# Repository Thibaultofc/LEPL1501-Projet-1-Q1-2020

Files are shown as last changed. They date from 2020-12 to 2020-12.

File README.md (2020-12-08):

# LEPL1501-Projet-1-Q1-2020
LEPL1501 - PROJET P1 – Q1 2020

Durant ce projet, nous avons été amené, par groupes de 6, à concevoir une grue flottante permettant d'assembler des éoliennes en mer. De surcroit, nous avons développé un programme permettant d'obtenir l'oscillation de la plateforme flottante lors du déplacement d'une charge. Finalement, nous avons conceptualisé certaines pièces sur Fusion 360 et nous les avons imrpimées à l'aide d'une imprimante 3D.

Les membres du groupe 11.27 sont *Thibault Lootvoet, Romain Loncour, Hugolin Louis, Nicolas Luyckx, Safiya Nouidei* et *Clara Nys*

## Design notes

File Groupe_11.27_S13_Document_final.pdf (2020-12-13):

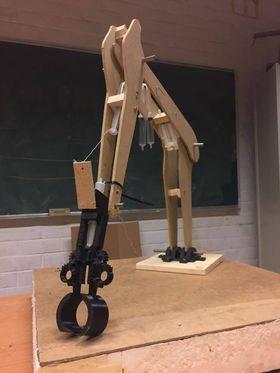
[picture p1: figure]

## LEPL1501 – PROJET P1 – Q1

### Décembre 2020

Groupe 11 .27 :

Thibault Lootvoet, Romain Loncour, Hugolin Louis,

Nicolas Luyckx, Safiya Nouidei et Clara Nys

## Table des matières:

## Introduction

Il y a maintenant près de deux mois, la famille de Bremaecker, persuadée que l'énergie éolienne est

encore trop peu utilisée, a demandé aux étudiants de l’EPL en Bac 1, de conceptualiser une grue ainsi

qu’une barge permettant d’assembler des éoliennes en pleine mer. Après avoir établi notre cahier des

charges, (repris à la page suivante), nous, le groupe 11.27, composé de Romain, Clara, Hugolin,

Nicolas, Thibault et Safiya, avons donc commencé à réfléchir à différents modèles.

En équipe, nous avons dû établir dans un premier temps toutes sortes de documents (To Do, cahier

des charges, organisation de l’équipe, …) afin que la progression du groupe se fasse dans les meilleures

conditions.

Après de nombreuses réflexions individuelles suivies d’échanges, nous en sommes arrivés à un modèle de grue fonctionnel que nous avons pu réaliser ensemble dans les délais et qui a parfaitement répondu aux exigences attendues par la famille, comme vous le verrez dans la conclusion.

Vous trouverez dans ce recueil toutes les parties du travail qui ont permis d’arriver au résultat escompté. Du cahier des charges à la construction du prototype, en passant par les schémas et le code informatique, chaque étape du processus est retranscrite dans ce document.

## Cahier des charges

Equipe 11.27

### Cahier des charges d’une grue

### flottante permettant de construire

### une éolienne

Date : 17-11-

2020

Mise à jour | Remplace : 2 Version du :
Date | Origine

Contexte : La famille De Bremaecker, très sensible aux questions environnementales et en particulier liées

à la production d’énergie, pense que l’énergie éolienne est trop peu utilisée. Ils décident donc de

sponsoriser un concours visant à promouvoir la recherche dans le domaine de la conception de grues

17-11-2020 | Equipe | Fonctions principales FP1. Pouvoir assembler toutes les parties d’une éolienne. FP2. La grue doit pouvoir être légère, facilement transportable, montable et
17-11-2020 | Equipe | Critères et niveaux des FP 1. L’éolienne a une hauteur totale de 210m, et 122m sans les pales. La grue doit pouvoir atteindre 122m.¹ 2. La grue doit pouvoir soulever jusqu’à 90 tonnes.² 3. Le grappin doit pouvoir saisir toutes les parties de l’éolienne y compris les
17-11-2020 | Equipe | Fonctions de Contraintes FC1. La grue doit être capable de flotter dans l’eau sans être submergée et tout en restant stable. FC2. La grue doit pouvoir résister aux intempéries en mer (températures, vent,
17-11-2020 | Equipe | Critères et niveaux des FC 1. La grue doit pouvoir résister à des températures allant de -19 degrés Celsius à 34°C⁴ 2. La pluviométrie s’élève jusqu’à 110.9mm.⁵ 3. La grue doit pouvoir résister à des rafales de vent allant jusqu’à 150km/h.⁶ 4. La hauteur des vagues maximales peut atteindre jusqu’à 20m.⁷

1 https://cpdp.debatpublic.fr/cpdp-eolienmer-pdlt/quelles-sont-caracteristiques-techniques-eoliennes-envisagees.html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,à%20environ%203%20600%20kg.
2 Idem 1
3 Idem 1
4 https://planificateur.a-contresens.net/europe/belgique/wallonie/la_cote/2793689.html
5 http://portail2.reseau-concept.net/Upload/siceco/fichiers/guide_enr_eolien.pdf
6 https://www.ifremer.fr/sextant_doc/dcsmm/documents/Evaluation_initiale/MMN/EE/MMN_EE_01_Climatologie_marine.pdf
7 http://www.geoclimat.org/2016/12/record-hauteur-vague-atlantique-nord.html

## Commentaires sur le CDC

Concernant son évolution, notre cahier des charges du début du projet était assez complet

sans pour autant nous restreindre donc nous avons décidé de le garder tel qu’il était. Cependant,

nous avons ajouté des sources et nous avons précisé les critères et niveaux des fonctions de

contraintes.

## Schéma cinématique de la grue réelle

Explication du schéma : Le schéma cinématique est composé de trois parties différentes à savoir le

système de rotation, le bras mécanique et le grappin. Ce dernier a été représenté de face par souci

de compréhension. Tous les mouvements que la grue effectue sont déclenchés par des seringues

représentées sur ce schéma comme des vérins hydrauliques. Le système de rotation transforme le

mouvement rectiligne de la seringue en mouvement de rotation à l’aide d’une liaison pivot entre la

seringue et un cylindre qui sort de l’engrenage. Il s’agit d’un système bielle-manivelle présent

notamment dans les moteurs à explosion. Cet engrenage en mouvement enclenche le mouvement

d’un autre engrenage sur lequel est disposé la grue. La grue en elle-même est constituée de 3 bras

mobiles reliés entre eux par des liaisons sphériques à doigt. Le grappin est composé d’une

crémaillère reliée à des engrenages encore une fois reliés à des engrenages sur lesquels sont fixées

les pinces du grappin.

## Conception du prototype

Premières idées

Plusieurs idées ont été émises et nous avons tous contribué à la conception de notre grue

finale. Au fil du projet, nous avons su rassembler nos idées pour créer un prototype que nous avons

pu peaufiner.

Trois étudiants avaient conceptualisé un grappin lors de la S4 et les trois autres une grue.

Nous nous sommes basés sur ces schémas pour élaborer notre premier grappin et la première

version de la grue.

La modélisation du grappin se fit en parallèle de la modélisation de la grue ce qui engendra

une incompatibilité des deux parties. Le règlement du concours stipulait que les morceaux

d’éoliennes étaient à prendre couchées et à redresser verticalement. Notre grappin était censé être

suspendu par des câbles à la grue mais malheureusement cela ne permettait pas de faire pivoter le

grappin.

Cheminement

La grue du pré-jury n’avait aucun lien avec notre grue finale. Ce sera explicité plus loin dans

le rapport. Comme expliqué précédemment, le grappin, bien que déjà modélisé et imprimé, s’est

révélé ne pas être la solution optimale pour le jury final. Voici tout de même quelques images de

celui-ci :

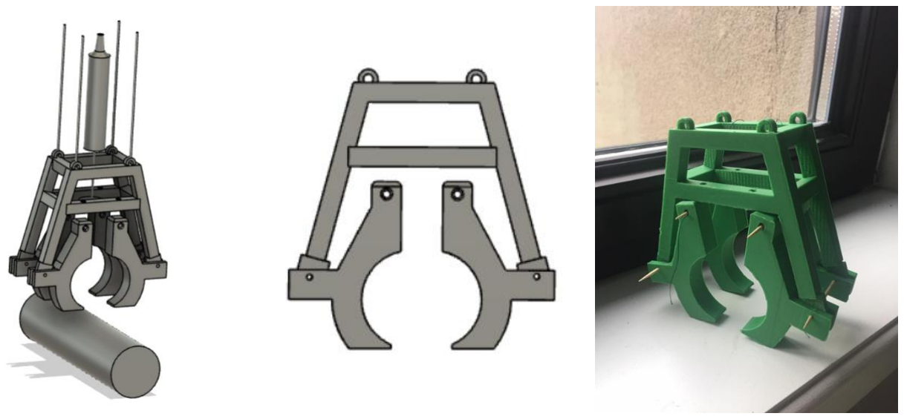
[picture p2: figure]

Après le pré-jury, nous avons repensé toute la modélisation pour remédier aux soucis rencontrés. Notre prototype se compose de quatre parties principales : le grappin⁹
, le bras articulé,

le système de rotation de la grue et la barge. Nous avons décidé qu’il serait le plus optimum de

construire un bras articulé. Constitué de trois parties et actionnable grâce au système de vérins, il

est posé sur le système de rotation. Le système de rotation fonctionne grâce à un engrenage qui est

enclenché par un autre engrenage qui est lui-même entrainé par le mouvement de la seringue. Ce

système est comparable aux roues d’une locomotive à vapeur.

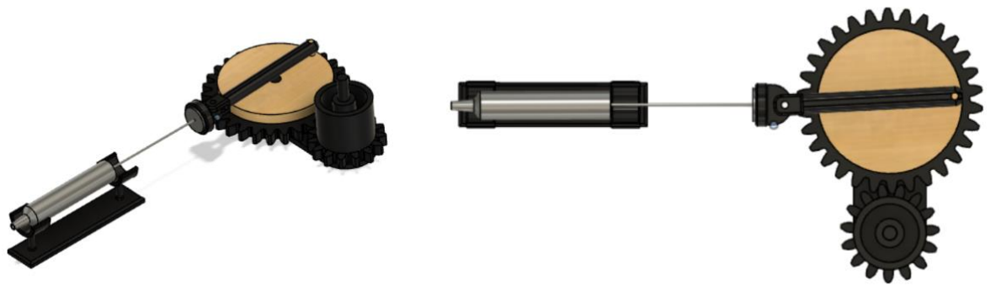
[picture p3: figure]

Le grappin, quant à lui, est également basé sur un dispositif d’engrenages et de crémaillère.

Voici le lien permettant d’accéder aux plans d'impression du grappin ( 6 fichiers stl ) : https://github.com/Thibaultofc/LEPL1501-Projet-1-Q1-2020

9 https://www.thingiverse.com/thing:2917515 Nous avons modifié cette pince afin de créer notre grappin.

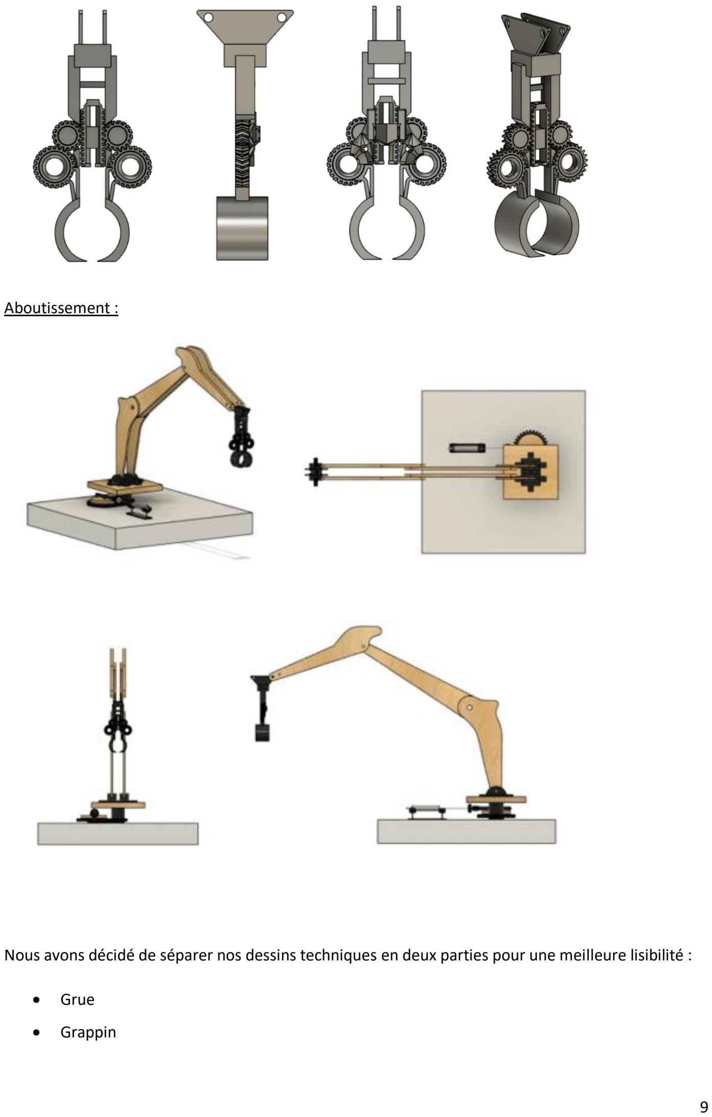
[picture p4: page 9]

Aboutissement :

Nous avons décidé de séparer nos dessins techniques en deux parties pour une meilleure lisibilité :

- Grue
- Grappin

Le grappin a dû être simplifié vu sa complexité. Les cotes des engrenages sont les cotes utilisées

pour caractériser plusieurs cercles et les cotes de certaines parties beaucoup trop complexes n’ont

pas été notées.

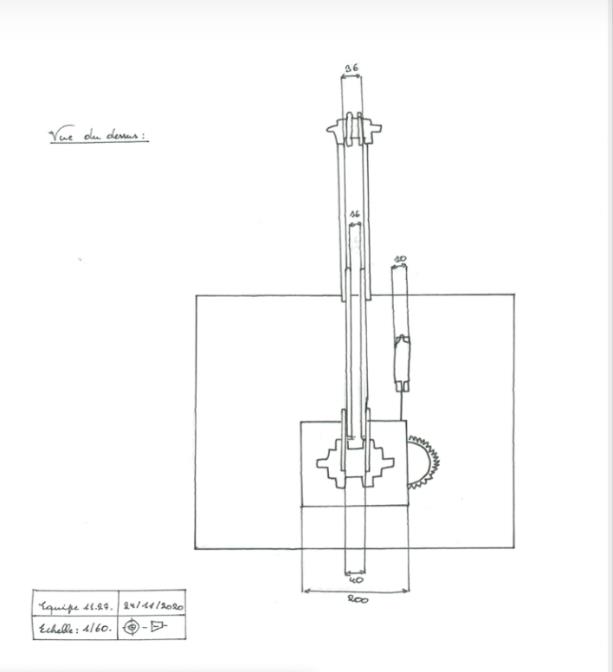
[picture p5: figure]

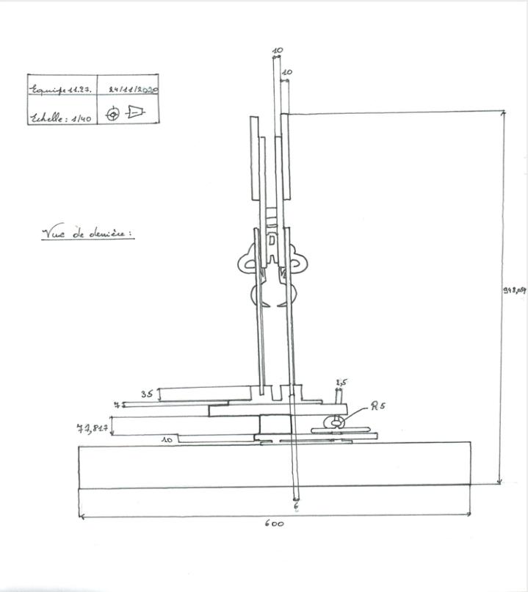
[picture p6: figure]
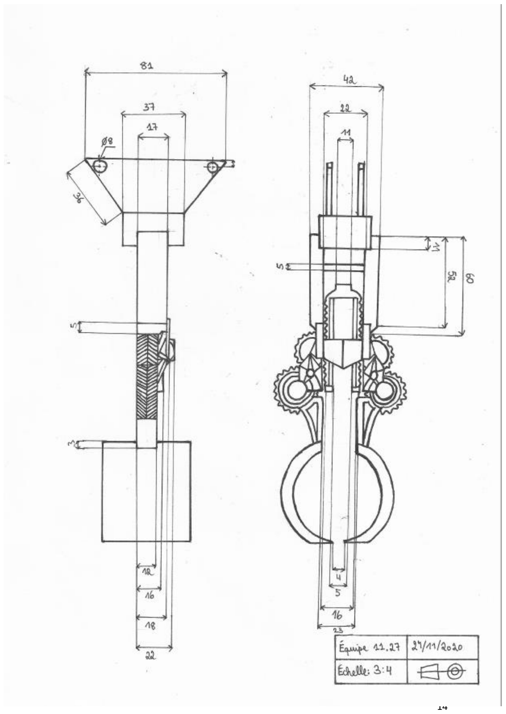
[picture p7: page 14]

## Modèle physique

Afin de modéliser le comportement de l’inclinaison de notre grue lorsqu’elle déplace une certaine

charge à une certaine distance, nous

avons procédé en deux étapes. De

plus, nous avons simplifié la

représentation de la grue afin de

simplifier les calculs tout en gardant

une précision acceptable. Le modèle

se compose d’une plateforme

flottante (m1), d’une charge placée

sur la plateforme (m2) et d’une

charge mobile (m3) à une certaine distance du centre de la plateforme (d).

Nous avons considéré que m2 était la masse du bras. Malgré le fait que nous avons placé la base

du bras à une extrémité, nous considérons quand même que m2 est placé au centre car le bras,

contrairement au modèle n’est pas un point et qu’après une analyse de notre prototype sur

Fusion 360, le centre de masse se situait approximativement au centre de la barge. Par contre, lorsque

nous déplaçons une masse nous considérons que cette charge est la somme de sa masse et de la

moitié du bras. De plus, nous considérons que l’angle au temps t = 0 est de 0 degrés.

Dans un premier temps, nous avons cherché à connaitre l’enfoncement de la plateforme dans

l’eau (1) et l’angle maximal que pouvait subir la plateforme avant d’être submergée en fonction de la

masse totale du système, de la charge déplacée et de la distance à laquelle celle-ci se situe du milieu

de la barge (2). L’équation (3) représente l’angle auquel la plateforme est en situation de soulèvement.

Le symbole φ représente la masse volumique du liquide dans lequel est plongé la plateforme (de l’eau dans ce cas-ci φ = 997 kg/m³
).

ℎc =

m1 + m2
L

2 ⋅ φ

(1)

θmax = arctan (

2(ℎ1 − ℎc

)
L
) | (2)

θs = arctan (

2ℎc
L
) | (3)

Dans un second temps, nous avons cherché à représenter le mouvement oscillatoire de la

plateforme lors du déplacement de la charge mobile (m3). Cette oscillation nous est donnée par

l’équation linéaire de second ordre suivante (4). I représente le moment d’inertie de la plateforme avec la grue, D représente le coefficient d’amortissement et C représente la somme des couples de

chavirement (5) et de redressement (6).

I

d

2θ
dt

2 + D

dθ
dt = C | (4)
Ca = m3gd′ | (5)
Cr = (m1 + m2)g|xc − xg| | (6)

Afin de calculer la distance d

′
(représentant la distance entre la masse et le centre en

fonction de l’angle) nous utilisons l’équation (7) qui est simplement un problème trigonométrique.

Afin de calculer les positions selon l’axe X du centre de gravité et du centre de poussée (xc et xg),

nous utilisons les équations (8) et (9).

d

′ = dcos(θ) − ℎ3sin(θ) | (7)

xg =

m1 (

ℎ1
2

− ℎc) + m2
(ℎ1 + ℎ2 − ℎc

)
m1 + m2
sin(θ) | (8)

xc =

(12)ℎc

2 − L

2
(24)ℎc

sin(θ) −

L

2
(24)ℎccos(θ)
tan(θ) | (9)

Pour les valeurs des différents paramètres, m1, m2, L, ℎ1, ℎ2 sont des paramètres

inhérents à notre grue tandis que m3, ℎ3, d, φ sont des paramètres dépendant du concours.

Finalement, nous avons considéré que g valait 9.81 m/s²
| Paramètres | Valeur / plage de valeurs
Paramètres de la grue | m1 Masse de la barge | 3 kg
| m2 Masse de la grue | 1.5 kg
| L Largeur de la barge | 0.6 m
| ℎ1 Hauteur de la barge | 0.15 m
| ℎ2 Hauteur de la grue | 0.5 m
Paramètres du concours | m3 Masse déplacée | 0 – 0.4 kg
| ℎ3 Hauteur de la masse déplacée | 0 – 0.6 m
| d Distance entre la grue et la masse déplacée | 0.6 – 1 m
| φ Masse volumique du liquide | 997 kg/m³ pour l’eau

## Description du fonctionnement du programme informatique

Le programme fonctionne de manière « pas-à-pas », c’est-à-dire qu’à chaque itération, le

paramètre dont toutes les équations dépendent (i dans ce cas-ci) est augmenté de 0.01 secondes.

Lorsque nous graphons la matrice dans laquelle nous stockons les données des angles en fonction du

temps, nous obtenons une sinusoïdale amortie. Afin d’être plus précis, nous pourrions diminuer la

valeur par laquelle le paramètre est augmenté, cependant dans nos tests, la précision donnée grâce à 0.01 secondes était suffisante (delta de l’angle de l’ordre de 10⁻⁴ degrés) et le temps de calcul passe

d’environ 1 seconde à plus de 10 secondes.

Le moment d’inertie a été déterminé grâce à Fusion360 et le coefficient d’amortissement a

été choisi en fonction de nos mesures en laboratoire (nous avons remarqué que la barge se stabilisait

après 10 secondes environ et par essai erreur nous avons trouvé le coefficient). Les autres paramètres

modifiables sont la masse déplacée, de la barge et de la grue, la distance à laquelle la masse est

déplacée, la largeur et hauteur de la base ainsi que la hauteur de la grue et de la masse. Le pas, la

durée et la masse volumique du liquide sur lequel la barge flotte peuvent aussi être modifiés.

## Simulations du mouvement d’oscillation

https://github.com/Thibaultofc/LEPL1501-Projet-1-Q1-2020

# Programme de simulation informatique produisant différents graphiques # Groupe 11.27

# Thibault, Clara, Nicolas, Romain, Hugolin et Safiya

import math
import matplotlib.pyplot as plt
import numpy as np

### Constantes

g = 9.81 | # Constante de gravitation [m/s^2]

### Paramètres du système

D = 10 | # coef d'amortissement
I = 6.596 | # Moment d'inertie [kg.m^2]
m = .4 | # Masse déplacée [kg]
m1 = 3 | # Masse de la barge [kg]
m2 = 1.5 | # Masse de la grue [kg]
mtot = m+m1+m2 | # Masse totale [kg]
d = 0.85 | # Distance [m]
L = 0.6 | # Largeur de la base carrée [m]
h1 = 0.15 | # Hauteur de la base [m]
h2 = 0.5 | # Hauteur du chargement [m]
h3 = 0.1 | # Hauteur de la masse portée [m]
hc = mtot/(L**2*997) | # 997 étant la masse volumique de l'eau [m]

### Paramètres de la simulation

step = 0.01 | # Pas (dt) [s]
end = 20 | # Durée [s]
x_0 = 0 | # Angle initial [rad]
x1_0 = 0 | # Vitesse angulaire initiale [rad/s]
x2_0 = 0 | # Accélération angulaire initiale [rad/s**2]
sum_c_0 = 0 | # Somme des couples initiaux [N.m]
Ca_0 = -m*g*d | # Couple initiale de chavirement [N.m]
Cr_0 = 0 | # Couple de redressement initial [N.m]
dist_0 = 0 | # Distance entre le centre de gravité et le centre de poussée selo
n X initiale [m]

### Matrices de stockage des données

t = np.arange(0, end, step) # Durée [s]
x = np.empty_like(t) | # Angle [rad]
x1 = np.empty_like(t) | # Vitesse angulaire [rad/s]
x2 = np.empty_like(t) | # Accélération angulaire [rad/s**2]
sum_c = np.empty_like(t) | # Somme des couples [N.m]
Ca = np.empty_like(t) | # Couple de chavirement [N.m]
Cr = np.empty_like(t) | # Couple de redressement [N.m]
dist = np.empty_like(t) | # Distance entre la barge et la charge [m]

xc = np.empty_like(t) | # Centre de poussée, coordonnée du x [m]
xg = np.empty_like(t) | # Centre de gravité, coordonnée du x [m]
distance = np.empty_like(t) # Distance en xc et xg [m]

def simulation(m):

# Equation: I*ang'' + D*ang' = C

### Paramètres initiaux de l'équation

x[0] = x_0
x1[0] = x1_0
x2[0] = x2_0
sum_c[0] = sum_c_0
Ca[0] = Ca_0
Cr[0] = Cr_0
dist[0] = dist_0

dt = step
P = mtot*g
Pa = m*g

# calcul pas-à-pas de l'EDO de second ordre. On stocke toutes les données dans chaque matrice res pective.

for i in range(len(t)-1):

dist[i+1] = d*math.cos(x[i])-h3*math.sin(x[i]) | # Distance
Ca[i+1] = -m*g*dist[i] | # Couple de chavirement

xc[i+1] = ((12*hc**2-
L**2)/(24*hc))*math.sin(x[i]) - (L**2/(24*hc*math.cos(x[i])))*math.tan(x[i]) # C entre de poussée, coordonnée en x
xg[i+1] = ((m1*(h1/2-hc)+m2*(h2+h1-
hc))/(mtot))*math.sin(x[i]) | # Centre de gravi
té, coordonnée en x
distance[i+1] = xc[i] - xg[i] | # Distance entre xc et xg

Cr[i+1] = mtot*g*abs(distance[i]) # Couple de redressement
sum_c[i+1] = Ca[i] + Cr[i] | # Somme des couples
x2[i] = (sum_c[i]-D*x1[i])/I | # Accélération angulaire
x1[i+1] = x1[i] + x2[i] * dt | # Vitesse angulaire
x[i+1] = x[i] - x1[i] * dt | # Angle
x2[i+1] = x2[i]

### Paramètres du graphique

angle_max = math.atan(2*(h1-hc)/L) | # Angle max
angle_s = math.atan(2*hc/L) | # Angle de soulèvement

### Variable permettant de passer de radians en degrés

rad_to_deg = 57.29578

r = rad_to_deg

### Graphique des différentes masses [kg] en fonction de la distance [m] à laquell e elles sont déplacées

def graphiques_distances_masses():

simulation(m)

# Traçage de chaque fonction pour chaque masse

simulation(1)
x_values = [0, d]
y_values = [x[0]*r, x[20]*r] plt.plot(x_values,y_values,label='m = 1kg') plt.legend()

simulation(2)
y_values2 = [x[0]*r, x[20]*r] plt.plot(x_values,y_values2,label='m = 2kg') plt.legend()

simulation(3)
y_values3 = [x[0]*r, x[20]*r] plt.plot(x_values,y_values3,label='m = 3kg') plt.legend()
simulation(4)
y_values4 = [x[0]*r, x[20]*r] plt.plot(x_values,y_values4,label='m = 4kg') plt.legend()

simulation(5)
y_values5 = [x[0]*r, x[20]*r] plt.plot(x_values,y_values5,label='m = 5kg') plt.legend()

# Paramètres généraux du graphique

plt.plot([0,end], [angle_max*r,angle_max*r], '--
r', label='submersion') # Ligne en pointillé qui marque le submersion (positif) plt.plot([0,end], [-angle_max*r,-angle_max*r], '--
r') | # Ligne en pointillé qui marque le submersion (négatif)
plt.plot([0,end], [angle_s*r,angle_s*r], '--
b', label='soulèvement') # Ligne en pointillé qui marque le soulèvement (positi f)
plt.plot([0,end], [-angle_s*r,-angle_s*r], '--
b') | # Ligne en pointillé qui marque le soulèvement (négatif)

plt.xlabel('Distance (m)')
plt.ylabel('Angle (º)')
plt.xlim(0,d)
plt.ylim(0,angle_max*r+1)
plt.show()

### Graphique de l'angle [degrés] en fonction du temps [s]

def graphique_angle_deg():

# Paramètres généraux du graphique

simulation(m)
plt.plot(t,x*r)
plt.xlim(0,end)
plt.xlabel('Temps (s)')
plt.ylim(0,angle_max*r+1)
plt.ylabel('Angle (º)')

plt.plot([0,end], [angle_max*r,angle_max*r], '--
r', label='submersion') # Ligne en pointillé qui marque le submersion (positif) plt.plot([0,end], [-angle_max*r,-angle_max*r], '--
r') | # Ligne en pointillé qui marque le submersion (négatif)
plt.plot([0,end], [angle_s*r,angle_s*r], '--
b', label='soulèvement') # Ligne en pointillé qui marque le soulèvement (positi f)
plt.plot([0,end], [-angle_s*r,-angle_s*r], '--
b') | # Ligne en pointillé qui marque le soulèvement (négatif)

plt.show()

### 3 graphiques :

# | 1. Angle [rad] en fonction du temps [s]

# | 2. Vitesse angulaire [rad/s] en fonction du temps [s]

# | 3. Accélération angulaire[rad/s**2] en fonction du temps [s]

def graphiques():

simulation(m)

# Sous-graphique : 1. Angle [rad] en fonction du temps [s]

plt.figure(1)

plt.subplot(3,1,1)
plt.plot(t,x, label="Angle")
plt.legend()
plt.xlim(0,end)

plt.plot([0,end], [angle_max,angle_max], '--
r', label='submersion') # Ligne en pointillé qui marque le submersion (positif) plt.plot([0,end], [-angle_max,-angle_max], '--
r') | # Ligne en pointillé qui marque le submersion (négatif)
plt.plot([0,end], [angle_s,angle_s], '--
b', label='soulèvement') # Ligne en pointillé qui marque le soulèvement (positi f)
plt.plot([0,end], [-angle_s,-angle_s], '--
b') | # Ligne en pointillé qui marque le soulèvement (négatif)
plt.ylabel('Angle \n (rad)',fontsize = 5)

# Sous-graphique : 2. Vitesse angulaire [rad/s] en fonction du temps [s]

plt.subplot(3,1,2)
plt.plot(t,x1,'g', label="Vitesse angulaire")
plt.legend()
plt.xlim(0,end)

plt.ylabel('Vitesse angulaire \n (rad/s)',fontsize = 5)

# Sous-graphique : 3. Accélération angulaire[rad/s**2] en fonction du temps [s]

plt.subplot(3,1,3)
plt.plot(t,x2,'#e3902b', label="Accélération angulaire") plt.legend()
plt.xlim(0,end)
plt.ylabel('Accélération angulaire \n (rad/s^2)',fontsize = 5)

# Paramètres généraux

plt.xlabel('Temps (s)')
plt.show()

### Diagramme de phase : graphique représentant la vitesse angulaire [rad/s] en fo nction de l'angle [rad]

def diagramme_de_phase():

# Paramètres généraux du graphique

simulation(m)
plt.title("Diagramme de phase") plt.plot(x, x1,linewidth=0.75) plt.xlabel("Angle (rad)")
plt.ylabel("Vitesse angulaire (rad/s)") plt.show()

### Programme principal

graphiques_distances_masses() graphique_angle_deg()
graphiques()
diagramme_de_phase()

## Graphiques

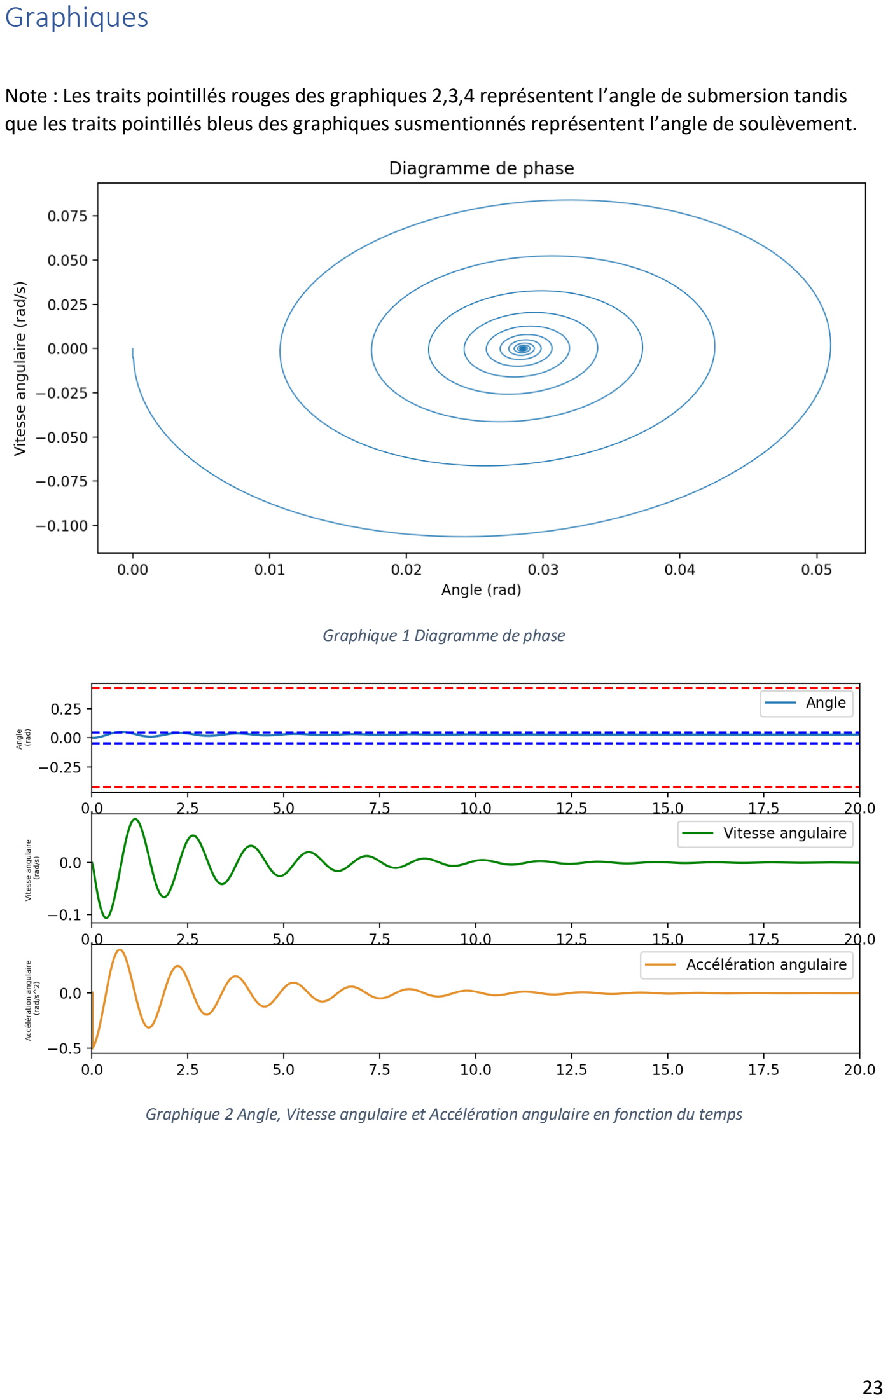
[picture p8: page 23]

Note : Les traits pointillés rouges des graphiques 2,3,4 représentent l’angle de submersion tandis que les traits pointillés bleus des graphiques susmentionnés représentent l’angle de soulèvement.

Graphique 1 Diagramme de phase

Graphique 2 Angle, Vitesse angulaire et Accélération angulaire en fonction du temps

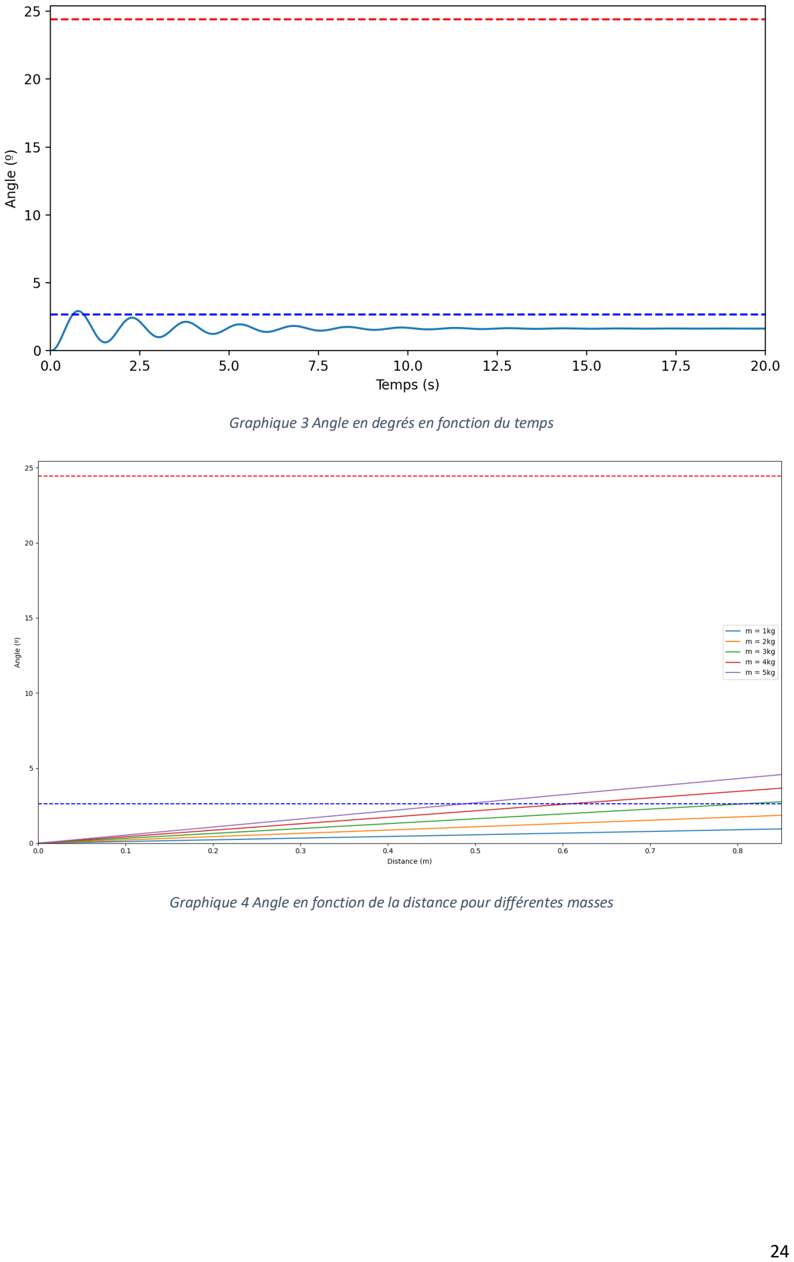
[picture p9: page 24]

Graphique 3 Angle en degrés en fonction du temps

Graphique 4 Angle en fonction de la distance pour différentes masses

## Discussion des résultats

Dans un premier temps, nous n’avions pas compris qu’au concours, l’inclinomètre serait remis

à zéro donc nous obtenions un angle bien trop élevé (entre 2 et 3 degrés alors que l’inclinomètre

indiquait 1.7 degrés). Après une modification, nous obtenons un angle de 1.66 degrés au temps t = 20,

résultat remarquablement proche de la réalité, malgré une simplification du modèle.

Le graphique 4, représentant l’angle en degrés en fonction de la distance, nous renseigne sur

le fait que notre barge ne risquait pas d’être submergée et qu’en soulevant les futs ou la tête de

l’éolienne, la barge n’allait pas être en soulèvement au temps t = 20 et c’est ce qu’il s’est passe en

réalité. En revanche, les graphiques 2 et 3 prévoyaient que la barge allait être en soulèvement lors de

la première oscillation et en pratique, un tel comportement n’a pas été observé.

En conclusion, notre modèle physique semble permettre de prédire l’angle final lors du

déplacement d’une masse, en revanche, il est imprécis quant aux oscillations. Afin d’améliorer les

résultats, il pourrait être intéressant de calculer le coefficient d’amortissement de manière analytique.

## Construction de la maquette

Pour le pré-jury, nous devions avoir une grue permettant de soulever une pièce de la grue a

une hauteur de 10 cm et avoir au moins 2 degrés de liberté. Pour répondre à ces exigences, nous

avions décidé de nous pencher sur un modèle de grue utiliser par les constructeurs à travers le

monde. C’est un modèle de bras télescopique se soulevant à l’aide d’un vérin hydraulique situé à la

base du bras. Un ancien jouet, redécouvert par un membre du groupe, nous a servi à faire le bras de

notre maquette. En effet, ce vieux jouet n’était qu’autre qu’une grue miniature. Il était en plastique

et reprenait exactement la même structure que les grues réelles. Il nous a donc paru judicieux de

l’utiliser car ce composant reprenant les caractéristiques souhaitées, la légèreté, la rigidité et la

facilité d’utilisation. La figure 1 permet mieux de visualiser notre maquette.

Ensuite, nous avons dû réfléchir à modèle de grappin. Nous

n’allons pas réexpliquer tout le cheminement que nous avons dû faire

pour aboutir à ce grappin mais en quelques lignes, le voici. Le grappin

devait donc pouvoir agripper un fut de 5 cm de diamètre et pouvoir

maintenir une pression suffisante pour que celui-ci ne glisse pas. Notre

premier modèle fut donc un modèle a « traction », autrement dit, la

force appliquée venait de la rétraction de la seringue. Il s’est avéré par

la suite que ce n’était pas le modèle le plus optimal. Ainsi, nous avons

décidé de changer de modèle mais ceci vous a déjà expliqué plus haut.

Comme le modèle définitif, le premier a été imprimé en PLA à l’aide

d’une imprimante 3D.

Avec ceci, nous n’avions qu’un degré de liberté, le verin à

la base servant à monter et descendre le bras (celui du grappin

est exclu). Pour palier a ce manque, nous avons ecidé d’incruster

un système de rotation. Celui-ci est situé a la base du bras et est

en réalité une grosse bobine de fil. En tirant à la main sur le fil

enroulé, il se déroule et entraine avec lui la bobine. Afin de

pouvoir faire tourner la grue à 360° et dans les deux sens

(horloger et anti-horloger), nous avons enroulé le deuxieme fil

dans le sens opposé au premier.

Enfin, voici un lien permettant de visionner une vidéo de notre maquette en action lors du pré-

jury :Test maquette : https://youtu.be/BV1qX7-c0VU

Figure 2 : modèle de grappin pour le pré-jury

Figure 3 : vue de haut de la maquette de pré-jury

## Construction du prototype

Dans un premier temps, nous nous sommes concentrés sur la

construction de la barge. Le matériau utilisé en guise de flotteur est un

panneau d’isolation. Comme le reste des éléments constituant cette

plateforme, il a été récupéré.

Nous avons choisi d’utiliser ce panneau isolant car tout d’abord, il est

de récupération. Il va de soit de, dans un premier temps, privilégier

l’utilisation de matière se trouvant en notre possession. Ensuite, ce matériau

a pour avantage d’être inaltérable à l’eau, ce qui n’est pas négligeable dans

notre cas. Enfin, il est relativement léger. En effet, il a une masse volumique

d’environ 30 kg/m³. Grâce à cela et sans poids supplémentaire, la barge

s’enfonce d’à peine 3 millimètres.

Dans un second temps, nous avons décidé d’imprimer la plupart des

pièces techniques en PLA, à l’aide d’une imprimante 3D. Ainsi, les

engrenages, axes, pieds de la grue, etc. ont été imprimés en 3D. Ce procédé

nous a permis de gagner du temps, de la précision et de l’énergie. Ensuite, le

matériau composant en grande partie la grue en tant que telle est le MDF.

Le MDF est un panneau composite de fibre de bois. Pour

notre utilisation, cela nous convenait parfaitement car le

prix était tout à fait abordable, la solidité suffisante et le

poids adéquat. De plus c’est un matériau simple

d’utilisation car il nous suffit d’une scie pour en faire ce que

l’on veut.

Dans une première idée, nous voulions découper

au laser les pièces dans des panneaux de bois.

Malheureusement, le COVID 19 ne nous a pas facilité la

tâche et a rendu impossible cette idée. Nous avons alors dû

découper les pièces manuellement. Finalement, en

comparant le prototype actuel avec la maquette réalisé en

S6, nous pouvons affirmer que notre modèle final est plus

efficace, plus esthétique et répond aux contraintes

imposées par notre cahier des charges.

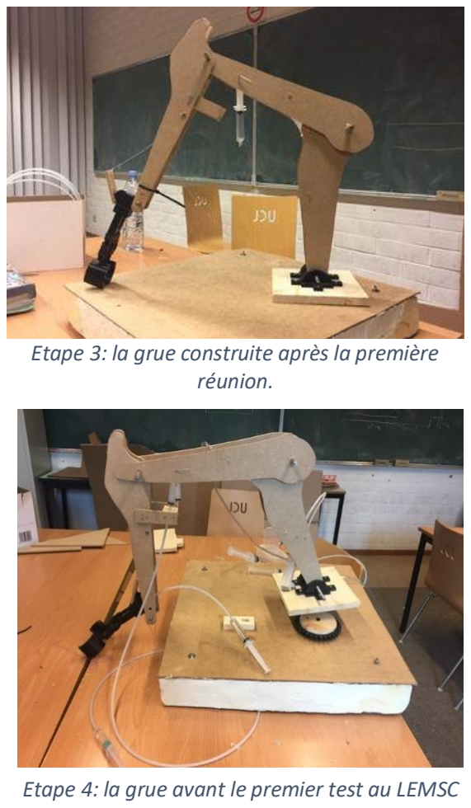
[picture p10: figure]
réunion.

Etape 3: la grue construite après la première

Etape 4: la grue avant le premier test au LEMSC

Etape 2: mise en place des éléments constitutifs de la grue

Les liens ci-dessous permettent de visionner les vidéos de notre prototype en action :

Test à sec : https://youtu.be/CDDwnzrw4-g

Test au LEMSC : https://youtu.be/yUPi21tc59Q

Vidéo du concours : https://youtu.be/ZDqFZTVV2L4

## Organisation de l’équipe

### - Contrat d’équipe :

1. Arriver à l’heure
2. Ne pas être absent de manière injustifiée
3. Respecter les échéances
4. Travailler de la manière la plus optimale
5. Respecter le groupe
6. Ecouter du groupe
7. Eviter les pertes de temps
8. Participer aux décisions
9. Participer activement au travail collaboratif

### - Commentaire :

Le contrat d’équipe a été globalement bien respecté par tous les membres du groupe tout au long

de ce projet. Nous avons eu, durant les premières semaines quelques soucis au niveau de

l’organisation et de la communication ce qui nuisait à l’optimisation du travail et du temps. Il nous est

arrivé de quelques fois rendre des travaux légèrement après l’heure d’échéance à cause de ce

problème d’organisation. Cependant, au fils des semaine et en apprenant à connaitre les membres du

groupe et leurs points forts, on a pu mieux se répartir les taches afin d’optimiser le rendement et la

qualité de nos productions finies.

Pour reprendre chaque point du contrat d’équipe, chacun des membres est arrivé à l’heure à

chaque cours de projet et si l’un de nous était absent, il prévenait à l’avance et avec une bonne excuse.

Ensuite, les échéances ont été bien respectées en ce fin de quadrimestre grâce à ce à quoi je fais

référence dans le paragraphe précédent. L’optimisation du travail s’est aussi améliorée au fils du

temps. Par ailleurs, le groupe a toujours su être respectueux de chacun, l’écoute et l’entraide était au

rendez-vous. Malgré le fait que certaines voix portent plus disons, nous avons tous pu nous exprimer,

exprimer nos idées et prendre part aux décisions.

Pour conclure, nous nous sommes améliorés au fils du temps et nous avons largement

respecté ce contrat d’équipe.

Coordonnées

Thibault.lootvoet@student.uclouvain.be

Romain.loncour@student.uclouvain.be

Clara.nys@student.uclouvain.be

Safiya.nouidei@student.uclouvain.be

Hugolin.louis@student.uclouvain.be

Nicolas.luyckx@student.uclouvain.be

Canal de communication : Teams et Messenger

### - Tableau de répartition des fonctions au fil du quadrimestre :

Fonction | S1 | S2 | S3 | S4 | S5 | S6
Gardien du temps | Clara | Thibault | Safiya | Romain | Hugolin | Nicolas
Animateur | Nicolas | Clara | Thibault | Safiya | Romain | Hugolin
Scribe | Hugolin | Nicolas | Clara | Thibault | Safiya | Romain
Porte-parole | Romain | Hugolin | Nicolas | Clara | Thibault | Safiya
Participant actif | Safiya | Romain | Hugolin | Nicolas | Clara | Thibault
Secrétaire | Thibault | Safiya | Romain | Hugolin | Nicolas | Clara

Fonction | S8 | S9 | S10 | S11 | S12 | S13
Gardien du temps | Clara | Thibault | Safiya | Romain | Hugolin | Nicolas
Animateur | Nicolas | Clara | Thibault | Safiya | Romain | Hugolin
Scribe | Hugolin | Nicolas | Clara | Thibault | Safiya | Romain
Porte-parole | Romain | Hugolin | Nicolas | Clara | Thibault | Safiya
Participant actif | Safiya | Romain | Hugolin | Nicolas | Clara | Thibault
Secrétaire | Thibault | Safiya | Romain | Hugolin | Nicolas | Clara

### - Evaluation de l’équipe :

Question 1 : Quel bilan faites-vous des résultats atteints par votre équipe ?

En termes de réalisation concrète (production de l’équipe) ?

Par exemple : la maquette ne permet pas tout à fait de comprendre la structure de l’engin, les points

suivants ont été bâclés, l’organisation de … est à conserver, etc.

- - Le grappin est fonctionnel malgré une grue qui ne ressemble pas à notre modèle final.
- - Le grappin n’était pas compatible avec notre modèle initial de grue donc nous avons dû

nous adapter

-En termes d’apprentissages réalisés ?

Par exemple : nouvelles habiletés que vous avez acquises suite aux notions abordées (travailler sur les

équilibres de forces, ...)

- - Nouvelles notions acquises en physique
- - Apprentissages au niveau de l’organisation :
- Déléguer les taches
- Se subdiviser en plus petits groupes

-En termes de participation et d’implication de chacun des membres de l’équipe ?

Par exemple : chacun des membres participe, certain·e·s se sont davantage impliqué·e·s dans le

travail, l’équipe est au complet etc. Illustrez vos propos par des faits concrets.

- - Tout le monde participait malgré le fait que l’équipe était rarement au complet
- Alors que Clara s’occupait de fusion, Thibault s’occupait des exercices physiques,

Romain et Nicolas s’occupaient de la maquette et Safiya et Hugolin s’occupaient à

tour de rôle de la maquette ou des exercices physiques

- De plus tout le monde a préparé les pitchs du lundi matin
- - On essayait de se diviser en groupes de 2 même si pour certaines tâches, on est

plus efficace en étant seul

Question 2 : Comment analysez-vous la démarche de travail et la coopération de votre équipe entre

la semaine 2 et la semaine 7 ?

-Quelle évaluation faites-vous de l’organisation de votre équipe ? Détaillez en illustrant par des

situations concrètes vécues au sein de l’équipe

Par exemple : le timing n’a pas été respecté, les tâches n’ont pas été réparties, etc. Pourquoi ? Quand

? Quels sont les faits ? Quelle résolution ?

- - Au début, gros problèmes avec les échéances (fait la veille) cependant à partir de la

semaine 6, on s’est beaucoup organisé (cf. le point au-dessus) et chaque tâche était

réalisée à temps.

- Nous avons commencé à plus communiquer sur Messenger au lieu d’utiliser

Teams™ et nous avons été plus efficace

-Comment a fonctionné la répartition des fonctions ? Détaillez en illustrant par des situations

concrètes vécues au sein de l’équipe.

Par exemple : les rôles ont été attribués, mais n’ont pas été tenus, etc. Pourquoi ? Quand ? Faits ?

Résolution ?

- Nous n’utilisons pas les rôles du tableau car chacun est polyvalent et le rôle de

chacun se fait en fonction des affinités des protagonistes

- Par exemple, Safiya faisait plus souvent la prise de notes et comme tout le monde

se respecte, nul besoin de porte-parole. Ensuite la gestion du temps était souvent

assurée par Thibault et les autres rôles étaient assurés par chacun.

-Chacun a-t-il pu s’exprimer ? Détaillez en illustrant par des situations concrètes vécues au sein de

l’équipe.

Par exemple : Les membres de l’équipe ne s’écoutent pas, certain·e·s restent en retrait, etc. Pourquoi

? Quand ? Faits ? Résolution ?

- Oui : pour les idées de la grue, chacun apporte son point de vue et au final on a une

solution qui reprend un peu des idées de chacun, de même pour le grappin.

-Comment ont évolué l’esprit de coopération et le climat de travail ? Détaillez en illustrant par des

situations concrètes vécues au sein de l’équipe.

Par exemple : L’équipe n’a pas réussi à se mettre d’accord, certain·e·s ne se sentent pas soutenu par

les autres membres de l’équipe, etc. Pourquoi ? Quand ? Faits ? Résolution ?

- Nous sommes devenus une équipe soudée
- Lors des APE et des APP, chacun s’entraide … si quelqu’un a un problème dans un

cours nous pouvons tous aider

Question 3 : Faites un bilan de la gestion des conflits au sein de votre équipe et tentez de dégager les

fonctions de leadership au sein de l’équipe. Par conflit, il ne faut pas entendre une confrontation

conflictuelle mais bien une confrontation constructive, un désaccord, une discussion sur une question

technique ou scientifique entre membres de l’équipe.

3.1 Quels sont les confrontations les plus utiles rencontrées par l’équipe ? Pourquoi les qualifiez-

vous d’utiles ?

Quoi ?

Modélisation de la grue

A quel(s) moment(s) ?

Tout au long des semaines

Description des faits :

Pendant 2h nous avons débattu du modèle de la grue à utiliser et au final nous sommes ressortis

avec une idée claire et précise de ce qu’il fallait faire

Qu’a apporté à l’équipe le fait d’avoir pu vous (re)mettre en accord ?

Nous avons une idée de ce qu’il faut faire et tout le monde est content

3.2. Certaines confrontations n’ont pu être résolues au sein de votre équipe, il reste des points de

désaccord dans l’équipe.

Quoi ?

Néant

A quel(s) moment(s) ?

Néant

Description des faits :

Néant

Que faudra-t-il mettre en place ?

Néant

Question 4 : Quelles sont les satisfactions et fiertés que vous avez rencontrées au niveau des

apprentissages réalisés, des réalisations atteintes, du travail en équipe (vos perceptions ont-elles

changé ou évolué) ?

Répondez en vous aidant des bilans individuels.

De quoi êtes-vous satisfaits ? De quoi êtes-vous fiers ? Commentez et expliquez par des faits

concrets.

a. Au niveau des apprentissages réalisés

Nous avons compris la modélisation physique et pouvions l’adapter à de nombreux cas malgré des

problèmes de compréhension au début

Nous avons appris à utiliser Fusion pour certaines et pour d’autres (Nicolas et Clara) c’était

l’occasion de mettre en application ce que nous avions appris auparavant b. Au niveau des réalisations atteintes

Nous avons réussi à produire une grue qui fonctionnait alors que nous pensions que nous allions

avoir quelque chose qui n’allait pas fonctionner

c. Au niveau du travail en équipe

L’ambiance de travail que nous avons créée est très plaisante et cela nous permet de nous sentir en

confiance et de ne pas avoir peur de partager nos impressions.

Question 5 : Quelles sont les déceptions et difficultés rencontrées au niveau des apprentissages

réalisés, des réalisations atteintes, du travail en équipe (vos perceptions ont-elles changé ou évolué) ?

Répondez en vous aidant des bilans individuels.

De quoi êtes-vous insatisfaits ? Qu’améliorer ? Commentez et expliquez par des faits concrets.

a. Au niveau des apprentissages réalisés

Néant

b. Au niveau des réalisations atteintes

Le modèle de la grue que nous avons présenté au pré jury n’est pas du tout représentatif du modèle

que nous allons faire pour le jury

c. Au niveau du travail en équipe

Tout le monde doit un peu plus se sentir concerné afin que nous puissions avancer de

manière plus efficace et avoir plus de temps pour réfléchir et assembler. En effet, nous

avions parfois une priorité sur un autre cours et ça nous a pénalisé

Question 6 : Quelles modifications pourriez-vous mettre en œuvre, quelles suggestions feriez-vous si

c’était à refaire ? Comment aimeriez-vous procéder et/ou qu’est-ce qui pourrait vous aider à le faire ?

a. Au niveau de la définition des objectifs

Diviser chaque sous-problèmes en sous-sous-problèmes afin de pouvoir avancer de manière plus

structurée

b. Au niveau des recherches d’informations et de l’apprentissage

Il faudrait être plus efficace (mieux se renseigner sur le sujet avant de travailler) par exemple pour

physique, nous ne comprenions pas et puis a un moment on a commencé à faire des recherches et

tout est devenu clair

c. Au niveau du travail d’équipe (organisation, implication, communication, etc.)

Mettre un agenda en place par exemple sur un Google docs.

Il faut que nous assignions les taches à l’écrit pour ne pas oublier ce qui doit être fait par qui et pour

quand.

d. Au niveau de la gestion des conflits et du leadership

Pas de problèmes à ce niveau-là.

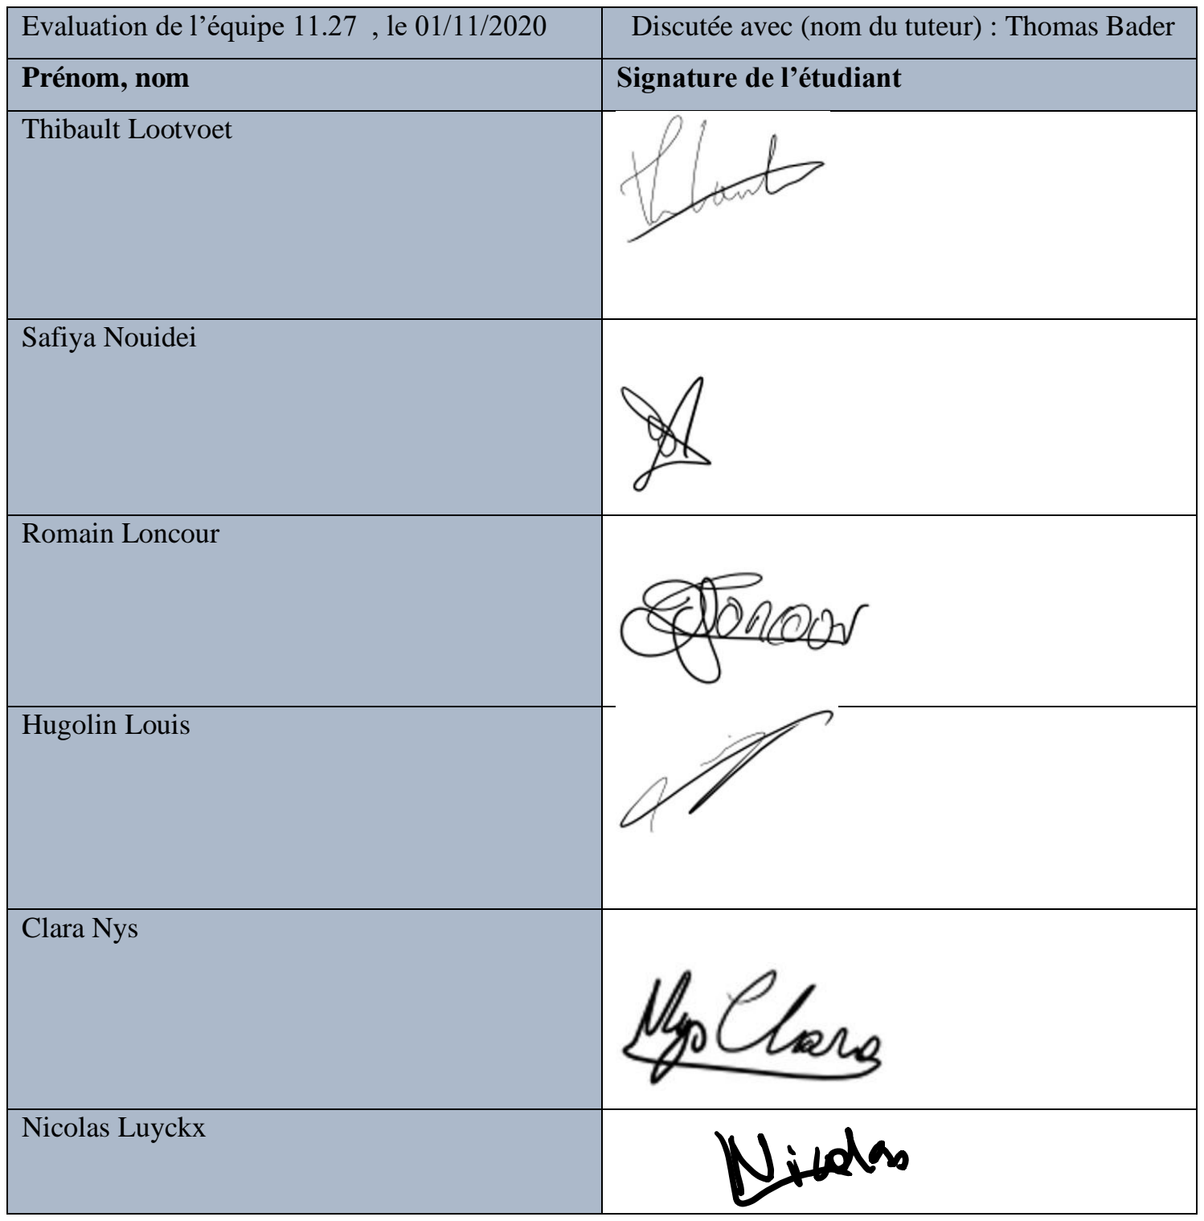
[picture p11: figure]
Prénom, nom; Signature de l’étudiant; Thibault Lootvoet; Safiya Nouidei; Romain Loncour; Hugolin Louis; Clara Nys; Nicolas Luyckx

Evaluation de l’équipe 11.27 , le 01/11/2020 | Discutée avec (nom du tuteur) : Thomas Bader

## Slides et commentaires

Slide 1 :

Ce premier slide contient les informations nécessaires à l’identification de notre groupe. En effet, le

numéro du groupe, nos noms, le code du cours et le nom de notre tuteur figurent sur cette page

d’accueil. De plus, nous avons décidé d’y placer une photo de notre groupe, prise a la fin de notre

concours, permettant de placer une image, et donc une meilleure identification de notre équipe.

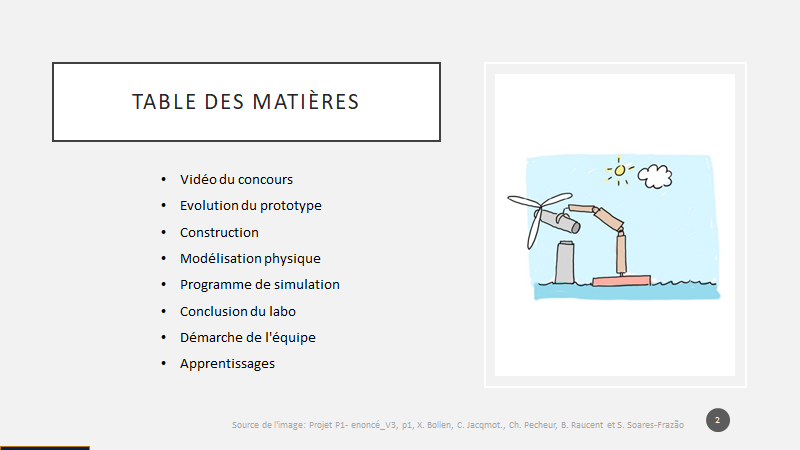
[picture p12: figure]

Slide 2 :

Table des matières

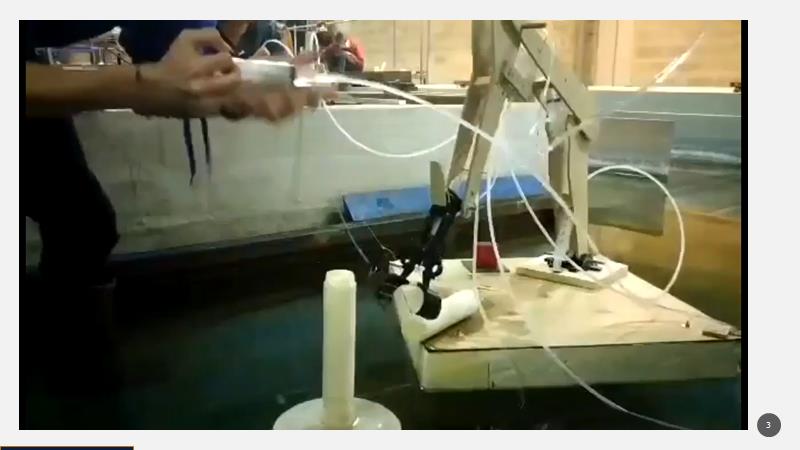
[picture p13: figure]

Slide 3 :

Voici une petite capsule résumant notre montage de l’éolienne lors du concours. Cette dernière a

été assemblée en 103 secondes et sans pénalité mais cela va être rappelé par la suite. La vidéo

originale est trop longue que pour être incrustée, nous l’avons donc découpé et dans la petite

capsule présente dans le PowerPoint, on y retrouve que les moments intéressants.

L’éolienne qui a servie lors su concours a été imprimé à l’aide d’une imprimante 3D. Le matériau

utilisé est le PLA, il est le plus souvent utilisé pour des impressions de ce type. Le concours s’est

déroulé dans un des laboratoires de l’UCL, le LEMSC (Laboratoire Essais mécaniques, Structures et

Génie civil). Il est dédié, comme le dis son nom, a toute sorte d’expériences dans le domaine de

l’ingénierie

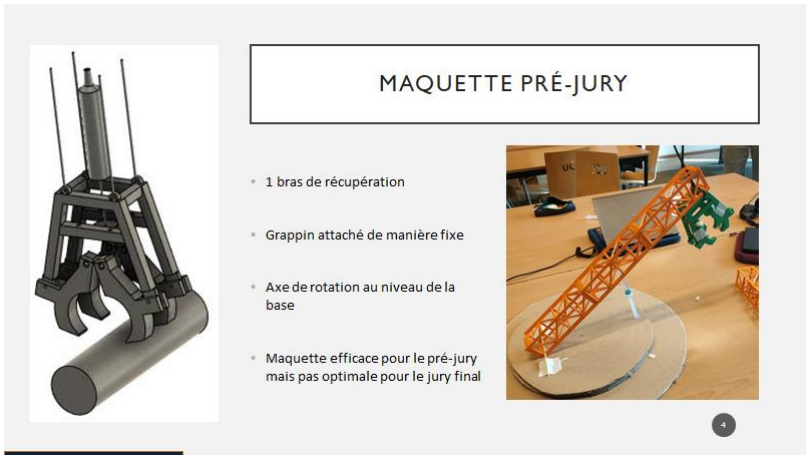
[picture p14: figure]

Slide 4 :

Ce modèle de grue permettait de fixer le grappin au bras sans intermédiaire de fil ce qui résolvait les

contraintes du prototype précédent.

Ce premier modèle de grappin était efficace pour le pré-jury mais ça n'était pas le bon choix pour le

concours.

Ce nouveau modèle ne répondait aux attentes du concours car le grappin ne pouvait attendre le sol

et ne redressait les futs étant donné qu'il soit fixé.

Lors de la présentation au pré-jury, nous avions émis l'idée d'installer un rail semi-circulaire au bout

du bras pour pouvoir remédier au problème de redressement, mais lors de la conception nous nous

sommes rendu compte que la tâche s'avérait plus compliquée que prévu et de multiples alternatives

s'offraient à nous.

Slide 5 :

Le schéma ci-dessus représente notre grue en action. On y peut voir, grâce aux flèches, les mouvements possiblement faisables. Ce schéma a été fait à la main et est à une échelle de 1 :60.

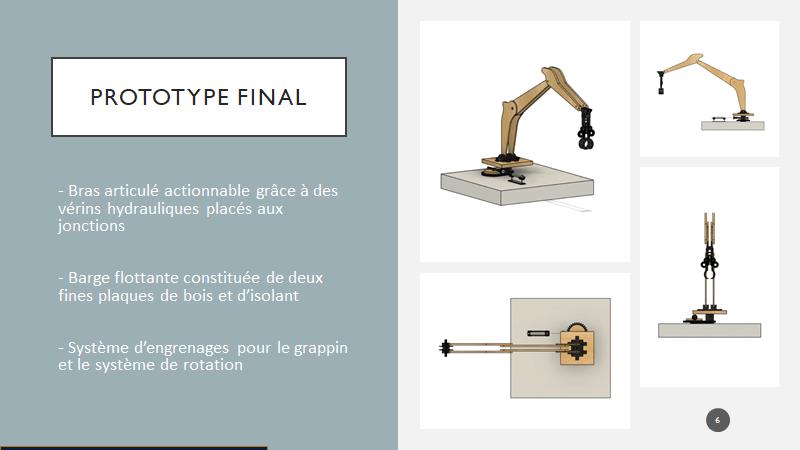
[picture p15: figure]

Slide 6 :

Ce prototype a été entièrement modélisé sur fusion 360 avant même sa construction, pour pouvoir

extraire les informations nécessaires à la simulation informatique. Les seringues et les jonctions ne

sont pas modélisées car nous n'étions pas sûr de leur position exacte. A nouveau, nous nous sommes

inspirés de modèle existant de pelleteuse car celle-ci répondait parfaitement aux attentes du

concours. Il permettait une prise plus simple des futs à sa base tout en conservant une extension

suffisamment grande pour atteindre le haut de l'éolienne. Le prototype est constitué en grande partie

de MDF. Ce matériau est résistant aux charges à porter tout en étant facile à découper/utiliser. Le seul

inconvénient de ce matériau est sa vulnérabilité face à l'eau. En effet, au contact de l'eau, il l'absorbe

et se gonfle et perds donc en résistance et gagne en poids. Grace à la stabilité de notre barge nous

savions qu'il n'y avait aucun risque que la grue prenne l'eau.

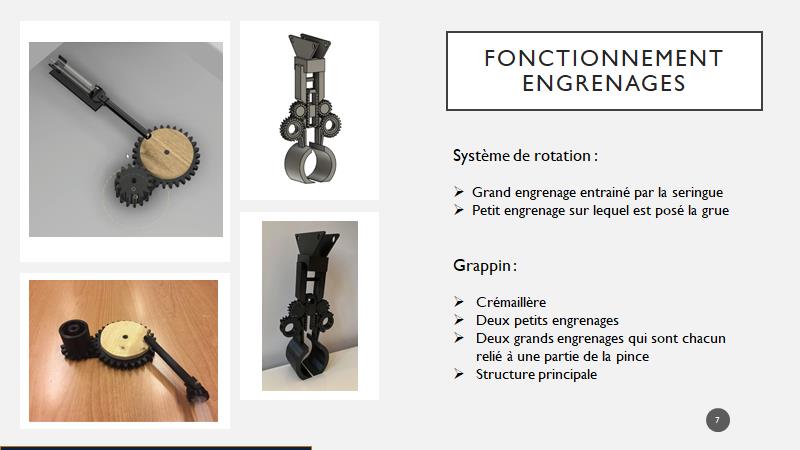
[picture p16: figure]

Slide 7 :

Les pièces constituant le système de rotation de la grue et du grappin étant à fabriquer soi-même nous

les avons donc imprimées en 3D. La matière d’impression est le PLA, elle est la plus commune à notre

niveau car elle est abordable et suffisamment résistante. Ainsi, notre grappin a été entièrement réalisé

en PLA. Contrairement au système de rotation de la grue, dont le fonctionnement est inspiré des

moteurs Stirling, qui lui a été en partie imprimé en 3D sauf le plateau tournant, auquel est accroché

le grand engrenage, réalisé en bois. Le fonctionnement de ce système est relativement simple. La

seringue fixe, en se déployant et se rétractant, entrainant avec elle, par le biais d’un bras de

repliement, le plateau tournant entrainant lui le grand engrenage. Ce dernier possède deux fois le

nombre de dents du plus petit. Cela signifie que en faisant un aller-retour avec la seringue,

théoriquement, le grand engrenage fait 360° tandis que le petit en fait 720°. Le pied de la grue étant

relié au petit engrenage, la grue est sensée faire 720 degrés lorsque la seringue fait un aller-retour

complet.

Slide 8 :

Grâce à ce dessin cinématique, on peut mieux comprendre le fonctionnement global de la grue. Le

grappin est disproportionné par rapport au reste par souci de clarté.

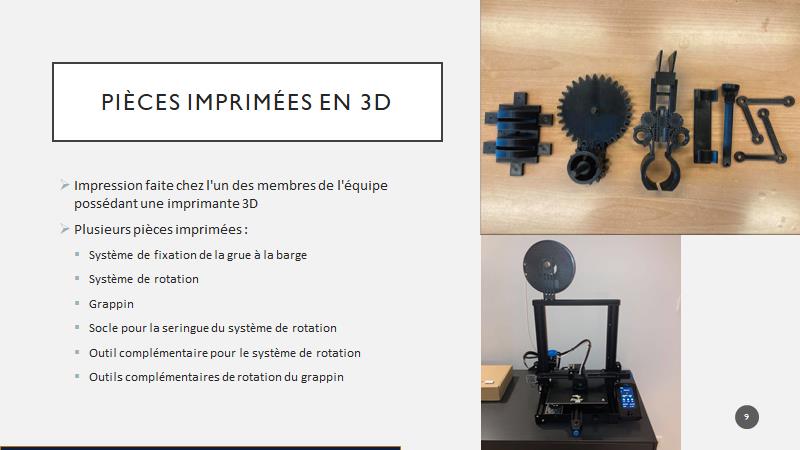
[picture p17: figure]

Slide 9 :

Par chance, un membre de notre groupe disposait d'une imprimante 3D capable de pouvoir imprimer nos pièces. Par soucis de facilité nous avons donc jugés qu'il était plus simple d'imprimer nous-mêmes nos pièces. Ainsi, nous pouvions éviter les déplacements à la BST au moindre problème d’impression. Evidemment, nos impression maison sont reprises dans la comptabilité.

Les pièces imprimées sont d'une complexité telle qu'il est trop difficile de les réaliser soi-même tout en conservant une bonne qualité.

Le système de fixation de la grue nous permettait de la fixer via 6 trous dans notre barge ce qui augmentait la stabilité de celle-ci.

Le grappin est tout simplement impossible à construire à la main car les pièces sont, comme vous le voyez, beaucoup trop détaillées que pour le fabriquer nous-même.

Slide 10 :

La construction s’est déroulée en 3 étapes principales : le rassemblement des éléments principaux et la construction de la barge, une première réunion pour faire le gros du travail (3ème photo) et enfin les

finitions. La barge est issue d’un panneau d’isolation en polyuréthane. Ce matériau a une masse

volumique d’environ 30 kg/m³. Si l’on calcule l’enfoncement de la barge nue, nous obtenons un

enfoncement de 5 millimètres. Sachant que la barge mesure 9 centimètres de haut, nous étions très

confiants quant à la flottaison de notre grue. De plus, lors du concours, nous avons calculé

l’enfoncement aux valeurs extrêmes et le résultat est d’autant plus rassurant car la barge s’enfonçait

de 25 millimètres dans le pire des cas.

Ensuite, notre organisation au niveau de la répartition des taches lié à la construction était assez

efficace car à chaque réunion de construction, nous étions trois au minimum avec, à chaque fois, tout

le matériel nécessaire (visseuse, foreuse, scie sauteuse, visses, tiges filetées, bois, …). Cela nous a

permis de bien nous répartir les tâches. Certains s’occupaient des documents à remettre (exercices

de physique, programme informatique, …) d’autres, plus habitués au travail manuel, s’occupaient de

la grue. Au total, il nous aura fallu 4 réunions pour rendre le prototype entièrement fonctionnel.

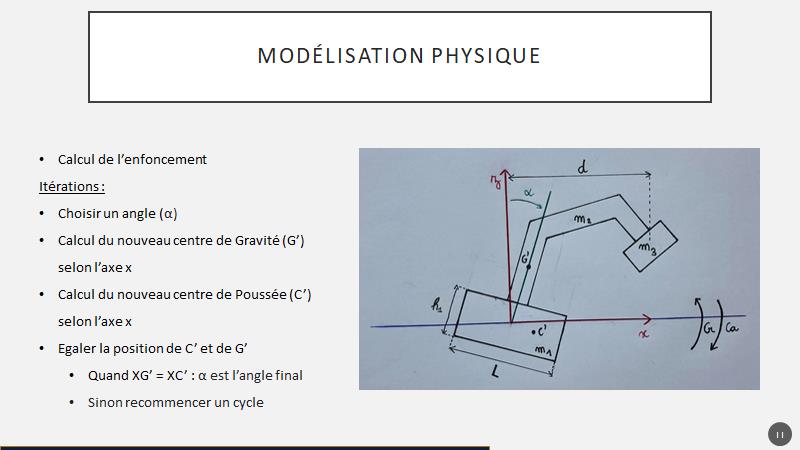
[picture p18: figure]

Slide 11 :

Concernant la modélisation physique, on a décidé de choisir le modèle où on néglige la masse m3 dans

le calcul du centre de gravité de la grue car nous avons jugé que cette masse est beaucoup plus faible,

et ainsi négligeable, comparée au poids total de notre grue, cela n'aurait donc que très peu d'impact

sur notre résultat.

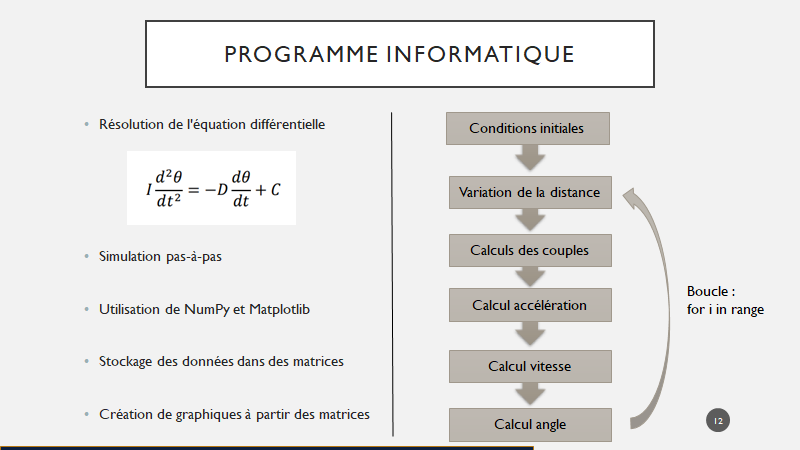
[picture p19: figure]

Slide 12 :

Le slide est divisé en deux ; à gauche, nous présentons les aspects plus techniques de la modélisation

tandis qu'à droite, nous expliquons les itérations que le programme effectue afin d'arriver à notre

résultat.

Nous présentons d'abord l'équation différentielle que nous avons résolu ; cependant, au lieu de la

résoudre de manière analytique, nous avons utilisé Python avec les modules math (pour pouvoir

utiliser des expressions mathématiques), numpy (pour pouvoir utiliser des matrices) ainsi que

matplotlib afin de pouvoir représenter de manière graphique nos résultats.

A droite, nous représentons de manière schématique notre programme à l'aide de flèches et d'une

boucle récursive. C'est une version simplifiée de ce qui se passe réellement dans notre programme ;

cependant, vous trouverez à la fin du PowerPoint des extraits de code.

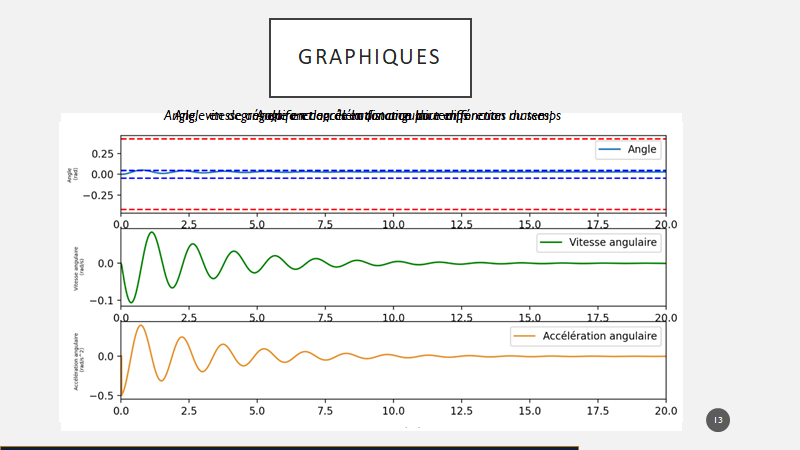
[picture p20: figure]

Slide 13 :

Ce slide affiche les différents graphiques produit par notre simulation informatique expliqué au slide précédent. A cause des animations, il est impossible de voir toutes les écritures et graphiques.

Slide 14 :

Globalement, on est assez content de notre résultat au concours, on est juste déçu car on a laissé une

erreur dans le programme informatique concernant l'angle d'inclinaison qui a donc faussé notre

estimation, mais celle-ci a été corrigé après le concours.

On a juste rencontré quelques problèmes car lors du test notre grue était placée sur un des côtés de

la barge et ne pouvait donc pas attraper les objets posés sur la barge. On a donc placé la grue sur un

des coins et retiré le système de rotation pour gagner en stabilité.

Lors du concours, on a éprouvé aucunes difficultés au niveau du placement de la barge, cependant, le

placement des pales était un peu plus difficile car notre grue était assez proche du lieu de construction

et donc le soulèvement de celle-ci devait être précis afin de ne pas percuter les 2 autres futs.

Concernant les seringues, celle-ci ont très bien fonctionné sans fuites car nous avions créé un joint

artificiel à l'aide d'un pistolet à colle et nous avons aussi acheté des seringues plus grosses pour

pouvoir exercer une force plus grande

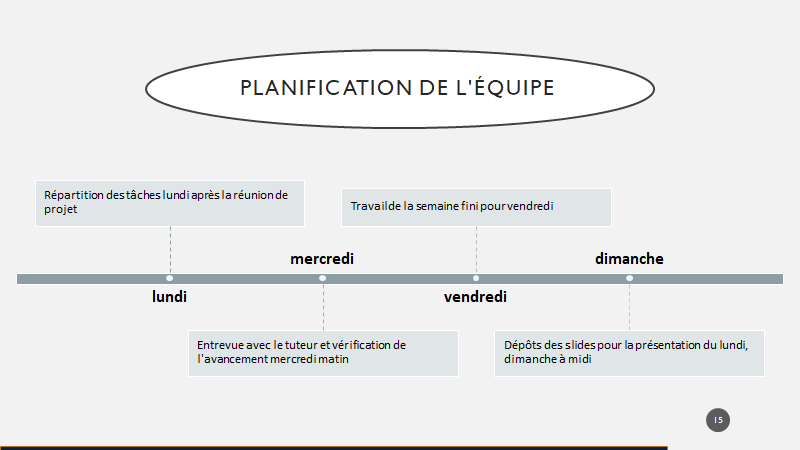
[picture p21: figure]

Slide 15 :

Concernant l'organisation de l'équipe, nous avons pris du temps à savoir respecter ce schéma mais

nous y sommes arrivés. C'était difficile de se coordonner et de travailler ensemble sur une partie du

projet étant donné que l'on ne se voyait jamais.

Pour la réalisation du PowerPoint, nous étions par groupe 2 et chaque semaine le binôme changeait.

Ainsi tout le monde travaillait sur la réalisation de celui-ci et pouvait s'entrainer à présenter si

l'occasion se présentait.

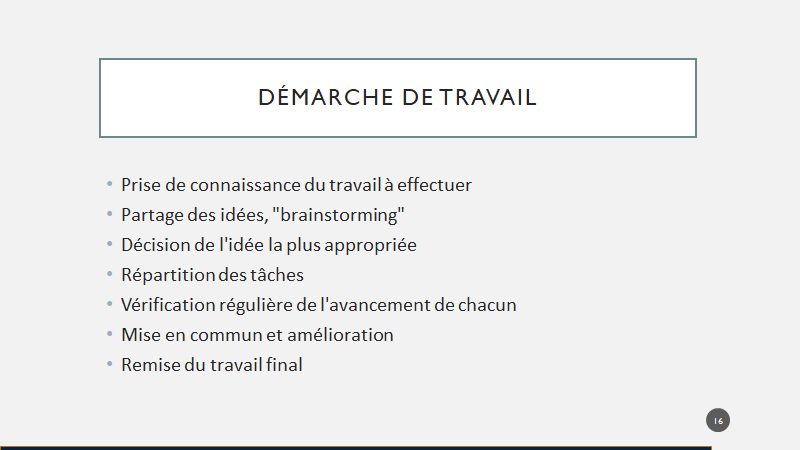
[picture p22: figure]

Slide 16 :

Concernant notre démarche de travail, nous avons au fil du temps établi une certaine routine. Celle-

ci est reprise clairement dans le transparent ci-dessus. Grace à cela, il nous était plus simple de

travailler ensemble car tout était clair pour tout le monde et nous savions à quoi nous en tenir. Ainsi,

nous étions plus efficaces car les taches étaient définies et les deadlines établies.

Slide 17 :

En finissant ce projet, nous avons réalisé que nos capacités dans de nombreux domaines se sont

beaucoup améliorées.

Tout d’abord, nos compétences en gestion de groupe et en travail de groupe ont énormément évolué.

Que ce soit dans la communication, l’organisation d’équipe ou encore dans la prise de responsabilités.

Nous avons tous évolué dans le bon sens.

Ensuite, nos connaissances théoriques ont-elles aussi décuplé. Nous avons exploré une multitude de

nouveaux aspects tel que la représentation de graphiques en python, les calculs de physique

(flottaison, équilibre, …). Ces connaissances sont, pour la plupart, issues de nos recherches

personnelles et ce mode de travail nous permet d’enregistrer ces notions beaucoup plus

profondément que lors d’un cours magistral.

Enfin, sur le plan plus pratique, nous avons aussi beaucoup appris. Le maniement de machines, telles

que des visseuses, des foreuses ou encore des scies sauteuses, était, pour certain, nouveau. C’était

donc une sorte d’initiation très fructueuse.

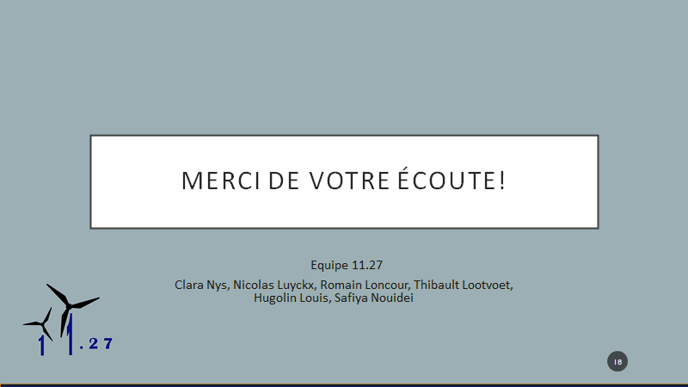
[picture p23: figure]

Slide 18 :

Merci de nous avoir écouté, c’était le groupe 11.27.

## Comptabilité

ACHATS | ACHETEURS | PRIX
Seringues (1) | Romain | 3.50€
Seringues (2) | Thibault | 2€
Seringues (3) | Nicolas | 1,80€
Tuyaux (1) | Nicolas | 1.50€
Plaques de bois | Nicolas | 6€
Bâtons de colle | Hugolin | 2,10€
Impressions 3D | Clara | 4 X 5€ = 20€
TOTAL | | 36,9€

Inventaires des pièces imprimées à domicile :

- Système de fixation de la grue à la barge
- Système de rotation
- Grappin
- Socle pour la seringue du système de rotation
- Outil complémentaire pour le système de rotation
- Outils complémentaires de rotation du grappin

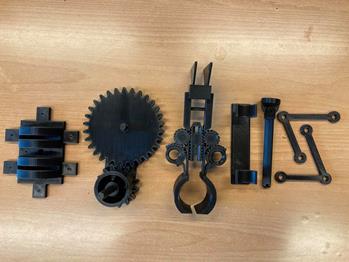
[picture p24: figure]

Nous avons été plutôt économes malgré le fait que les impressions augmentent fortement notre

budget. Pour des raisons techniques, nous n’avons pas fait d’impressions à la BST lorsque nous

sommes passés en distanciel. Si nous calculons réellement le prix que cela nous a couté sachant

qu’une bobine de 1 kilo de PLA coûte 20 euros ayant utilisé au grand max 500 grammes de fils nos

approximations se rapprochent plus de 10 euros. Mais nous avons quand même mis 20 euros pour

correspondre à 4 impressions qui doivent être comptées pour 5 euros chacune. De plus, nous

n’avons pas pu récupérer des seringues et tuyaux vu la rupture de stock, c’est pour cela que nous

avons dû en acheter à plusieurs reprises.

## Conclusion

Pour rappel, le défi initial était de construire une grue flottante capable d’assembler une

éolienne en mer. Après de deux mois de dur labeur, nous avons réussi à en créer un prototype à petite

échelle entièrement fonctionnelle. Evidemment, le modèle final n’a pas été conçu du premier coup, il

nous a fallu plusieurs essais, qui à chaque fois présentaient encore des défauts et ce n’est qu’en

apprenant de nos erreurs que nous avons débouché sur le modèle de grue que nous avons utilisé lors

du concours. En effet, lors du pré-jury, nous avions à peine un bras, actionné grâce à un piston, un

grappin fonctionnel mais loin d’être optimal et une plateforme en carton.

Heureusement, notre équipe était performante, efficace et soudée et cela nous a permis de

pouvoir avancer a pas sûr et a une allure relativement constante et élevée. La communication dans le

groupe s’est améliorée au fil des semaines, l’atmosphère n’a, elle aussi, cessé de se rendre plus

agréable et chaleureuse mais à la fois productive.

Le bilan final de ce premier projet est très positif, nous avons tous acquis beaucoup de

compétences au niveau des travaux de grande envergure en groupe, la gestion d’équipe, la

communication mais aussi au niveau des sujets traités, tels que les modélisation 3D, l’approche

technique et manuelle.

Enfin, la petite cerise sur le gâteau qui vient clôturer ce projet de manière encore plus positive

est le fait que l’on ait réussi à empiler les 3 futs de l’éolienne lors du concours en un temps

relativement faible (1min43). Ceci conclut donc ce rapport sur notre projet du premier quadrimestre.

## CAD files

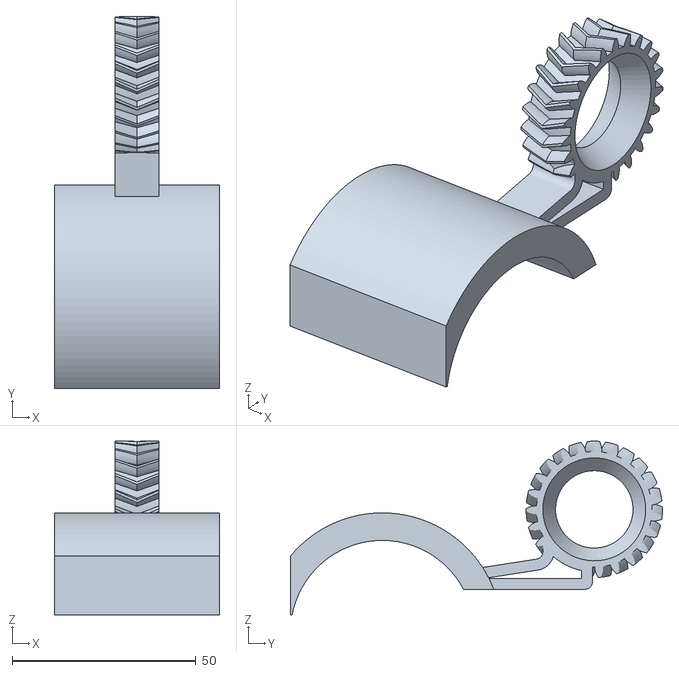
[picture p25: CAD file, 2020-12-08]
Pince droite.stl
45.0 x 101.3 x 47.3

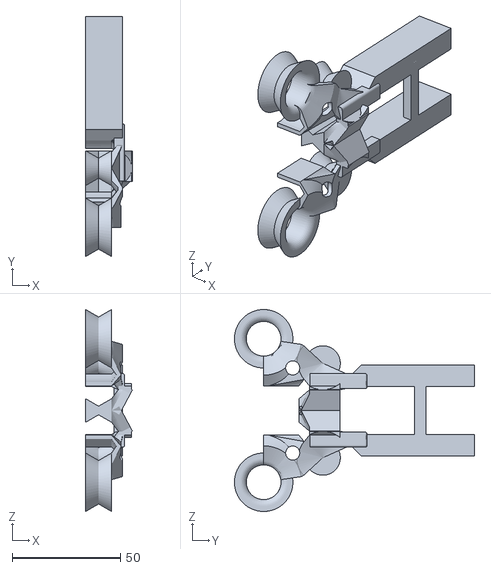
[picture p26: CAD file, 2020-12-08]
Corps.stl
21.6 x 110.8 x 93.2

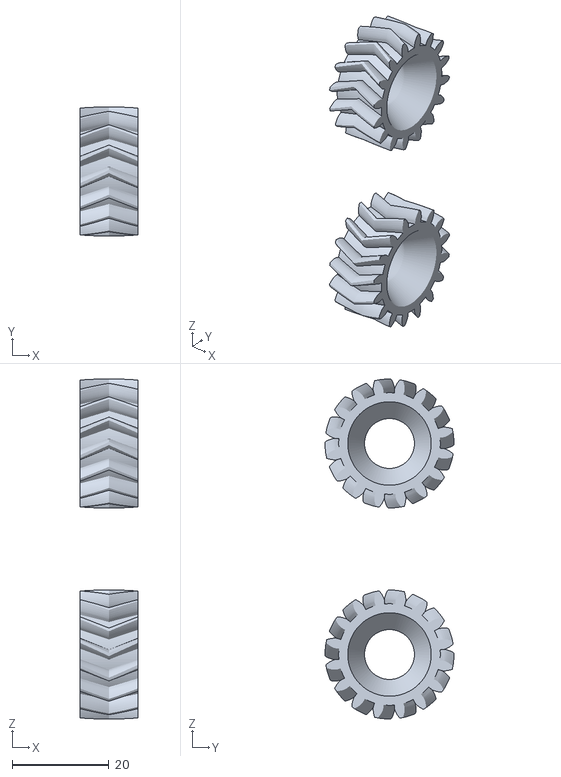
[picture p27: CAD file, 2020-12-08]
Petits engrenages.stl
12.0 x 26.6 x 70.2

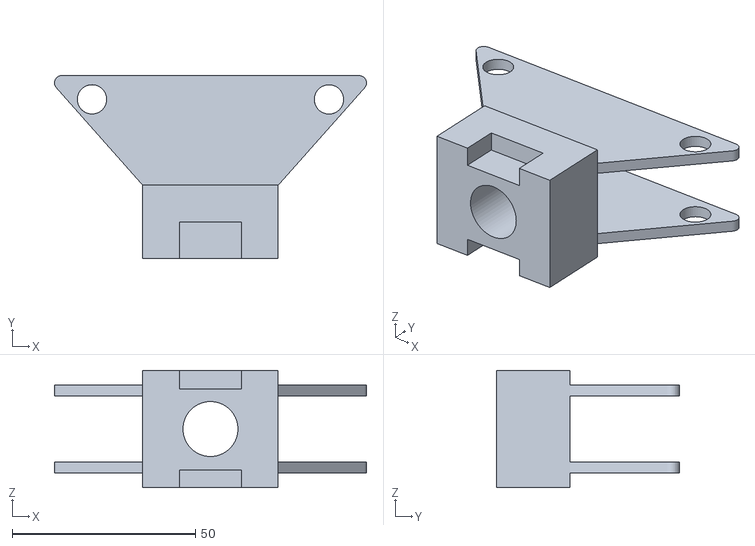
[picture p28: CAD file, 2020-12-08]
Haut du grappin.stl
85.2 x 49.9 x 32.0

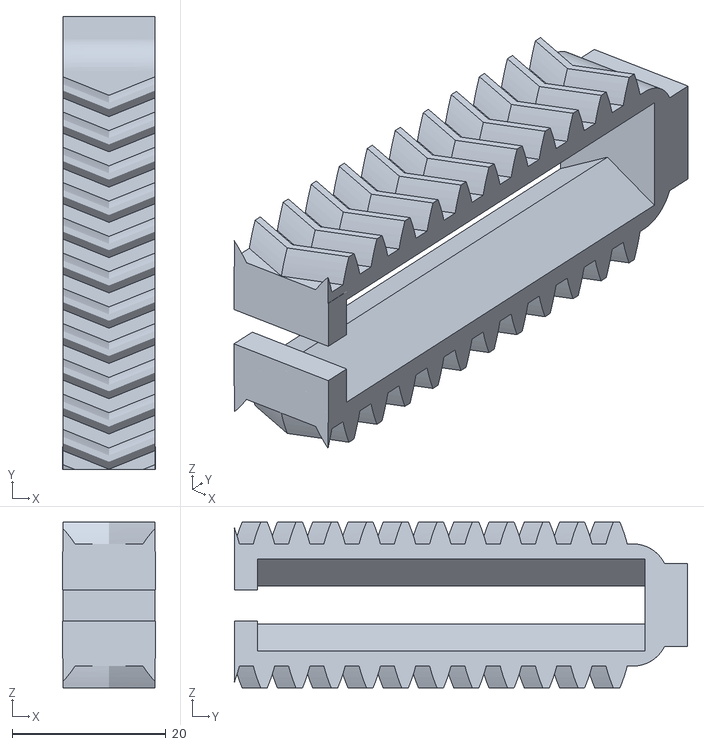
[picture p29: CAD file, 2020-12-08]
Crémaillière.stl
12.1 x 59.0 x 21.6

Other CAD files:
Pince gauche.stl
